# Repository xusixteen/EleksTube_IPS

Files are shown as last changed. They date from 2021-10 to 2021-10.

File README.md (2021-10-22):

# EleksTube_IPS
## 时间线变动器

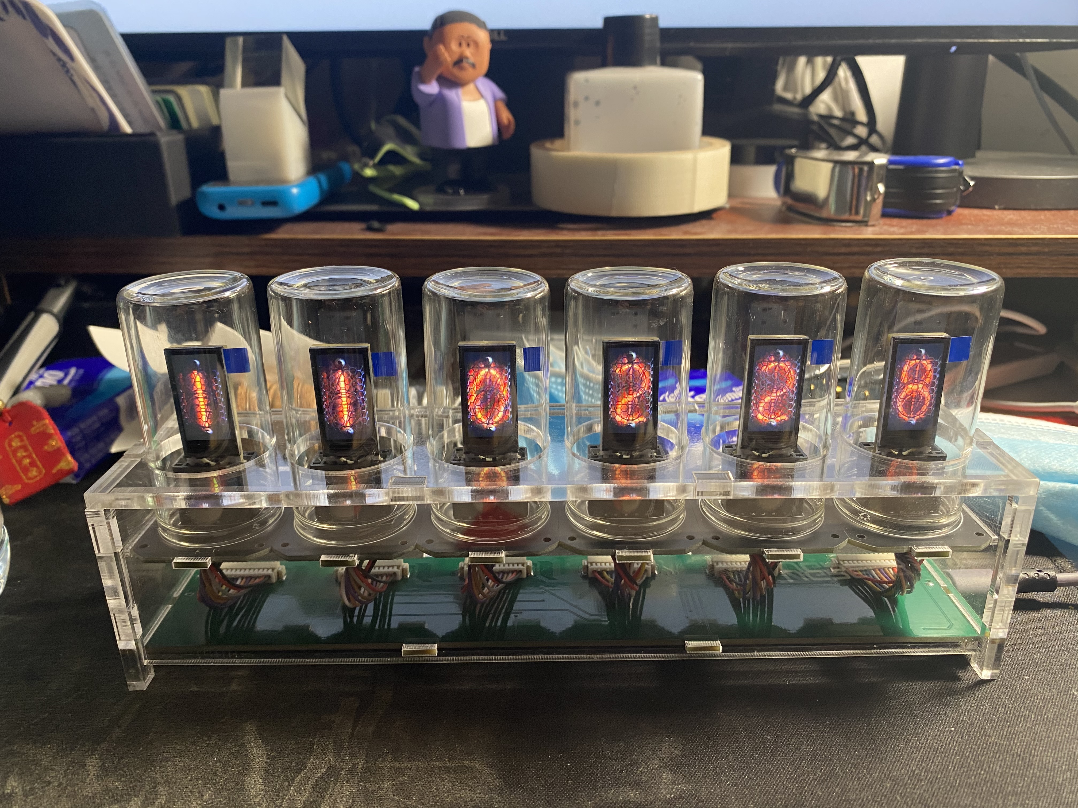
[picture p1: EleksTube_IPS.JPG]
EleksTube


### 代码上参考了https://github.com/xusixteen/EleksTubeIPSHack
### 网络同步时间参考了https://github.com/ClimbSnail/HoloCubic_AIO
### 硬件设计与原版EleksTube不兼容，主要表现在屏幕小板的13pin金手指改成了12pin的板间连接器

#### TFT屏幕是0.96寸 80*160分辨率 驱动ST7735
### 现存不足
#### 1、ESP-WROOM-32D自动下载电路存在问题，改为外部按键控制GPIO0与EN复位。
#### 2、EN引脚需外加10K上拉电阻和0.1uF对地电容。
#### 3、RX与TX接反，R8与R3需要飞线交换。
#### 4、main与midextend板间1.27mm排线需采用反向12p。
#### 5、按键封装需旋转90°。

### TODO
#### 1、整合IMU功能。
#### 2、增加SD卡或利用内部FLASH，增加图案。
#### 3、增加有线同步时间功能。上位机运行脚本获取网络时间，通过串口发送至ESP32。

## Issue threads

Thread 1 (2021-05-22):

Original  elekstube ips boards

RedNax67, 2021-05-22:
These boards aren't compatuble with the current design which uses 13 connections. The problem with the current design is that vdd and leda are connected together which makes dimming the displays not possible. Could you do a design with these connections seperated out?

xusixteen, 2021-05-23:
i am looking for the original dlekstube design as well. and not quite get your point about the problem in current design. Netlable BLK is uesd to control the backlight of the tft screen. when BLK is low, Q1 cut off,back light led off.when BLK is high or leave open ,back light is on.

RedNax67, 2021-05-23:
By applying a pwm to led a through a p channel mosfet it would be possible to dim the display brightness. But since, in the current design, it's joined with vdd to the controller, applying pwm will give problems (it does, i tried). Also gnd is commoned which is now used to turn the display (and backlight) off through an n channel mosfet.  To be clear, with backlight i mean the LEDA backlight of the display, not the ws28.. leds on the bck of the board.

xusixteen, 2021-05-23:
Thank you for pointing out this .
of course it will be better to tuning the lcd brightness ,not only on/off  two states.i have fix this in v1.1 version.
i have not get the project done,so if i am glad  you can get another try ahead.

RedNax67, 2021-05-23:
Good luck with the project!  so far you're the only one i've found doing hardware for this. Alternate firmware is now readily available.

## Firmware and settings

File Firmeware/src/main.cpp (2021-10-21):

#include <Arduino.h>
#include "Hardware.h"
#include "ChipSelect.h"
#include "TFT_eSPI.h"
#include "time.h"
#include "Clock.h"
#include "alert.h"
#include "number.h"
#include "UpdateTime.h"
#include "ESP32Time.h"
#include "network.h"

uint64_t chipID;
ChipSelect chip_select;
uint8_t digits[NUM_DIGITS];
boolean time_to_sync = false;
//TFTs tfts;    // Display module driver
TFT_eSPI tft = TFT_eSPI();
extern ESP32Time g_rtc; // 用于时间解码

extern String time_api;
extern String ssid;
extern String password;
void setup() {
  // put your setup code here, to run once:
  Serial.begin(115200);
  chipID = ESP.getEfuseMac();
  Serial.printf("ESP32 Chip ID = %04X",(uint16_t)(chipID >> 32));
  Serial.printf("%08X\n",(uint32_t)chipID);
  
  chip_select.begin();
  chip_select.setAll();

  pinMode(TFT_ENABLE_PIN, OUTPUT);
  digitalWrite(TFT_ENABLE_PIN, LOW);
 

  tft.begin();
  tft.setRotation(0);	// landscape

  // Swap the colour byte order when rendering
  tft.setSwapBytes(true);
  // Draw the icons
//  UpdateDisplay(force);
// tft.pushImage(0, 0, dig_Width, dig_Height, dig_0);
//  delay(2000);
//  connect_wifi_get_time();
  for (uint8_t digit=0; digit < NUM_DIGITS; digit++) digits[digit] = 0;
  //Update_time_display();
  tft.pushImage(0, 0, dig_Width, dig_Height, dig_0_9);
  network_init(ssid, password);
  long long timestamp = getTimestamp(time_api) + (28800000); //nowapi时间API
  g_rtc.setTime(timestamp / 1000);
  uint8_t hh = g_rtc.getHour(true);
  uint8_t mm = g_rtc.getMinute();
  uint8_t ss = g_rtc.getSecond();


  SetDigit(HOURS_TENS, hh / 10, force);
  SetDigit(HOURS_ONES, hh % 10, force);
  SetDigit(MINUTES_TENS, mm / 10, force);
  SetDigit(MINUTES_ONES, mm % 10, force);
  SetDigit(SECONDS_TENS, ss / 10, force);
  SetDigit(SECONDS_ONES, ss % 10, force);


}


void loop() {
  // put your main code here, to run repeatedly:
  if (time_to_sync){
    network_reconnect();
    long long timestamp = getTimestamp(time_api) + TIMEZERO_OFFSIZE; //nowapi时间API
    g_rtc.setTime(timestamp / 1000);

    time_to_sync = false;
  }
  Update_time_display();


//  Serial.printf("system running\n");
//  Serial.printf("ESP32 Chip ID = %04X",(uint16_t)(chipID >> 32));
//  Serial.printf("%08X\n",(uint32_t)chipID);
}

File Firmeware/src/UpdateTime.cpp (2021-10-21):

#include "Arduino.h"
#include "UpdateTime.h"
#include "network.h"
#include "ESP32Time.h"
#include "ChipSelect.h"
#include "TFT_eSPI.h"
#include "number.h"
#include "common.h"

String ssid = "7#5802";
String password = "7#58027#5802";
String time_api = "http://api.m.taobao.com/rest/api3.do?api=mtop.common.getTimestamp";
#define WIFI_LIFE_CYCLE 60000 // wifi的生命周期（60s）

unsigned long m_preWifiReqMillis; // 保存上一回请求的时间戳
long long m_preNetTimestamp;         // 上一次的网络时间戳
long long m_errorNetTimestamp;         // 网络到显示过程中的时间误差
long long m_preLocalTimestamp;       // 上一次的本地机器时间戳
unsigned long timeUpdataInterval = 5000;    // 日期时钟更新的时间间隔(900s = 900000 / 2)
unsigned long preTimeMillis;         // 更新时间计数器

uint8_t network_connect_status = 0;
#define not_connect 1 
#define connecting 2
#define connected 3

extern ChipSelect chip_select;
extern uint8_t digits[NUM_DIGITS];
extern boolean time_to_sync;
//TFTs tfts;    // Display module driver
extern TFT_eSPI tft;

boolean m_wifi_status;            // 表示是wifi状态 true开启 false关闭
Network g_network; // 网络连接
ESP32Time g_rtc; // 用于时间解码
long long getTimestamp(String url)
{
    String time = "";
    HTTPClient http;
    http.setTimeout(1000);
    http.begin(url);

    // start connection and send HTTP headerFFF
    int httpCode = http.GET();
    Serial.printf("httpCode is %03d\n",httpCode);
    // httpCode will be negative on error
    if (httpCode > 0)
    {
        //Serial.printf("httpCode > 0\n");
        if (httpCode == HTTP_CODE_OK)
        {
            //Serial.printf("HTTP_CODE_OK\n");
            String payload = http.getString();
            Serial.println(payload);
            int time_index = (payload.indexOf("data")) + 12;
            time = payload.substring(time_index, payload.length() - 3);
            // 以网络时间戳为准
            m_preNetTimestamp = atoll(time.c_str()) + m_errorNetTimestamp;
            m_preLocalTimestamp = millis();
            Serial.printf("synchronized time from network successfully!\n");
        }
    }
    else
    {
        Serial.printf("[HTTP] GET... failed, error: %s\n", http.errorToString(httpCode).c_str());
        // 得不到网络时间戳时
        m_preNetTimestamp = m_preNetTimestamp + (millis() - m_preLocalTimestamp);
        m_preLocalTimestamp = millis();
    }
    http.end();

    return m_preNetTimestamp;
}
void network_init(String ssid, String password)
{
	Serial.println("scan start");
	int n = WiFi.scanNetworks();
	Serial.println("scan done");
	if (n == 0)
	{
		Serial.println("no networks found");
	}
	else
	{
		Serial.print(n);
		Serial.println(" networks found");
		for (int i = 0; i < n; ++i)
		{
			Serial.print(i + 1);
			Serial.print(": ");
			Serial.print(WiFi.SSID(i));
			Serial.print(" (");
			Serial.print(WiFi.RSSI(i));
			Serial.print(")");
			Serial.println((WiFi.encryptionType(i) == WIFI_AUTH_OPEN) ? " " : "*");
			delay(10);
		}
	}
	Serial.println("");
	Serial.print("Connecting: ");
	Serial.print(ssid.c_str());
	Serial.print(" @");
	Serial.println(password.c_str());

	WiFi.begin(ssid.c_str(), password.c_str());
	while (WiFi.status() != WL_CONNECTED)
	{
		delay(500);
		Serial.print(".");
	}
	Serial.println("");
	Serial.println("WiFi connected");
	Serial.println("IP address: ");
	Serial.println(WiFi.localIP());
}
void network_reconnect()
{
  switch (network_connect_status)
  {
    case not_connect:
    	if (WiFi.status() != WL_CONNECTED)//修改连接状态
    	{
        Serial.println("");
        Serial.print("Connecting: ");
        Serial.print(ssid.c_str());
        Serial.print(" @");
        Serial.println(password.c_str());
        WiFi.begin(ssid.c_str(), password.c_str());

        network_connect_status = connecting;
      }
      break;
    case connecting:
      if (WiFi.status() == WL_CONNECTED)
      {
        network_connect_status = connected;
      }      
      else{
        Serial.print(".\n");
      }
      break;
    case connected:
      Serial.println("");
      Serial.println("WiFi connected");
      Serial.println("IP address: ");
      Serial.println(WiFi.localIP());
//      String time = g_rtc.getTime(String("%H:%M:%S"));
//      Serial.printf("time is : %s\n",time); 
      network_connect_status = not_connect;

      break;
    default:
      break;
  }
}

void Update_time_display(){

    uint8_t hh = g_rtc.getHour(true);
    uint8_t mm = g_rtc.getMinute();
    uint8_t ss = g_rtc.getSecond();
    if ((hh == 8) && (mm == 8) & (ss == 8)){
      time_to_sync = true;
    }
    SetDigit(HOURS_TENS, hh / 10, force);
    SetDigit(HOURS_ONES, hh % 10, force);
    SetDigit(MINUTES_TENS, mm / 10, force);
    SetDigit(MINUTES_ONES, mm % 10, force);
    SetDigit(SECONDS_TENS, ss / 10, force);
    SetDigit(SECONDS_ONES, ss % 10, force);

    String time = g_rtc.getTime(String("%H:%M:%S"));
    //display_time( time.c_str());
    Serial.printf("time is : %s\n",time);    
}



void ShowDigit(uint8_t digit){//刷新单个数字显示
  chip_select.setDigit(digit);
  switch (digits[digit])
  {
  case 0:
    tft.pushImage(0, 0, dig_Width, dig_Height, dig_0);
    break;
  case 1:
    tft.pushImage(0, 0, dig_Width, dig_Height, dig_1);
    break;
  case 2:
    tft.pushImage(0, 0, dig_Width, dig_Height, dig_2);
    break;
  case 3:
    tft.pushImage(0, 0, dig_Width, dig_Height, dig_3);
    break;
  case 4:
    tft.pushImage(0, 0, dig_Width, dig_Height, dig_4);
    break;
  case 5:
    tft.pushImage(0, 0, dig_Width, dig_Height, dig_5);
    break;
  case 6:
    tft.pushImage(0, 0, dig_Width, dig_Height, dig_6);
    break;
  case 7:
    tft.pushImage(0, 0, dig_Width, dig_Height, dig_7);
    break;
  case 8:
    tft.pushImage(0, 0, dig_Width, dig_Height, dig_8);
    break;
  case 9:
    tft.pushImage(0, 0, dig_Width, dig_Height, dig_9);
    break;                  
  default:
    break;
  }

}
void SetDigit(uint8_t digit, uint8_t value, show_t show) {//更新数字
  uint8_t old_value = digits[digit];
  digits[digit] = value;

  if (show != no && (old_value != value || show == force)) {
    ShowDigit(digit);

  }
}
